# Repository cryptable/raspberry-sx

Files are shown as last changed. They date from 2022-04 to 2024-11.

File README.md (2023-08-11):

# raspberry-sx

Cyberdesck based on old [Commodore 64 SX](https://en.wikipedia.org/wiki/Commodore_SX-64). 

It uses a Raspberry Pi 4 with Wifi and 8Gb memory. There is an SSD attached to it using one of the USB 3.0 ports. The other USB 3.0 is used to attach a USB hub. On the USB 2.0 port is a keyboard attached and the other USB 2.0 port is used for the touch screen. It is powered by a powerbank, which is charged using a power supply. There is much place left in the cyberdeck to add other measuring instruments or a Pi modules cluster. 

It is open-source and you can adapt the design as you wish as long as you send me a pictures of your usage with a explanation of usage. 

And when we meet in person, you can also buy me a beer. 

More information is found under the [docs](./docs/cyberdeck-body.md).

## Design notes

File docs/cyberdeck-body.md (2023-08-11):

Cyber-deck
==========

Introduction
------------

We build a cyberdeck which is modifiable for other to extend. It is designed using a casco, which can be extended using other material.
The casco is designed to be waterproof (rainproof), maybe submergable proof.
It is all 3D printed, but the casco can also industrialised be build. You will a 3D printer with a bed 300x300 and a height 400. 

Casco
-----

The design of casco is done in FreeCAD and found in the .\design-folder. It exists out of a front panel containing the keyboard, a body with a front plate and back plate and a backpanel to store the power cable.

The frontpanel contains the Raspberry Pi, Screen, SSD and USB hub. It also has a place to store a mouse or other things.
The backpanel has the connector for ethernet, a cooler and the connector of the powersupply.

Mainboard and Screen
--------------------
- Raspberry Pi4 8Gb
- Wisecoco 5.5 inch FullHD screen
- Ice Tower

The Rapsberry Pi4 8Gb memory in attached to the Wisecoco 5.5 inch FullHD screen with ontop the Ice Tower. You can reuse all the screws and bolds of the Ice Tower and the Wisecoco screen to attach teh Raspi. You will need to shorten the small screws of the Ice Tower to fin into screws of the Wise coco.

You attach the HDMI connection from the screen to the Raspi, but you don't use the touch screen connection, because we will not sacrifice a USB 3.0 port just for a touch screen. We use a small USB-A to micro USB cable (10cm) to make the connection. We need the USB 3.0 ports for the USB 3.0 SSD and USB hub.

Keyboard
--------

see [keyboard](./cyberdeck-keyboard.md)

Power for cyberdeck
-------------------

Power is delivered by a powerbank supporting USB-PD and able to deliver 30W. The USB-C is used to power the Raspberry Pi with its periferals. This is charged by 70W power supply, which means you can use the powersupply for other usages. The 5V of the powersupply is connected to the micro-USB of the powerbank to charge the powerbank.

References
- MEAN WELL Well 1439455 LRS-75-5 AC Power Supply Block Closed 14A 70W 5 V/DC
- Poweradd Energycell II Powerbank PD 30 W, 26800 mAh Power Bank with Power Delivery

Power on and off
----------------

### Naive implementation

The first try was to powering on and off through a switch, which will shutdown the raspberry Pi. But I couldn't start it again. Also the active cooler on the CPU stayed running, proving the raspberry Pi was still drawing power of the powerbank.

### Second try

I build a latched controlled by a Raspberry Pico (with a small 0.96" displayed attached to it) using a MOSFET to switch on the Raspberry Pi and switch it the powerbank off after a shutdown of the Raspberry Pi.
Due to the voltage drop over the MOSFET, because the Pi with the periferals draws a substantial current, I didn't have enough voltage left to run the Raspberry Pi.

### Third solution

I use a USB-PD supported voltage requestor (DollaTek), which can be set to higher voltage, like 12V. In between comes the latch with the micro-controller and after the latch will a buck converter which will output 5V and power the Raspberry Pi.

### Fourth solution

The micro-controller controls a latching relay.

### References:
- https://www.embeddedcomputing.com/technology/open-source/development-kits/raspberry-pi-power-up-and-shutdown-with-a-physical-button
- DollaTek Snellaadtrigger PD/QC/AFC - ondersteunt vaste spanning 5V 9V 12V 15V 20V van USB-C
- Hailege XL4015 DC-DC Buck Converter Step Down Module 4 ~ 38 V op 1,25 – 36 V 5 A DC-DC verstelbare step-down module XL4015 4 ~ 38 V 96%
- Latching Relay FeatherWing

Lids of Cyberdesk with locks
----------------------------

The lids of the cyberdeck a locked using stainless steel levers.

reference:

- Miuse ZS0307-1 Toggle Latch, Stainless Steel Lever, Lock Cap, Lock for Case Box, Toolbox, Drawer, Cabinet, Chest, Pack of 8
- https://www.thingiverse.com/thing:4094861
- https://www.thingiverse.com/thing:5222235

Mouse case lid idea
-------------------

https://www.thingiverse.com/thing:2609754

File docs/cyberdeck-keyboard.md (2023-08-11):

Introduction
============

USB cable loose:

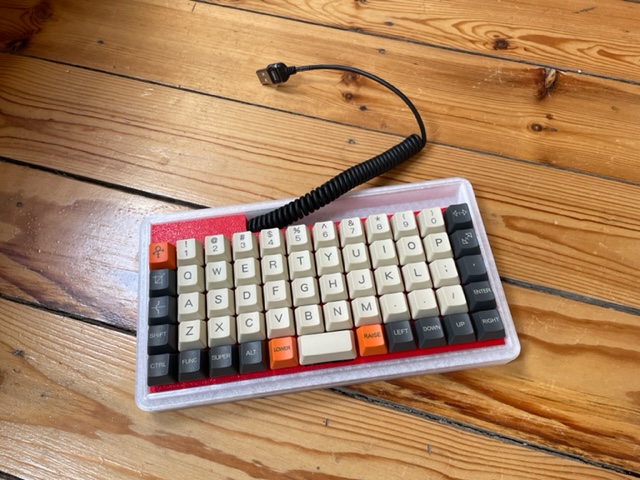
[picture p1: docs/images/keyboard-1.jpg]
Keyboard


USB cable tucked away:

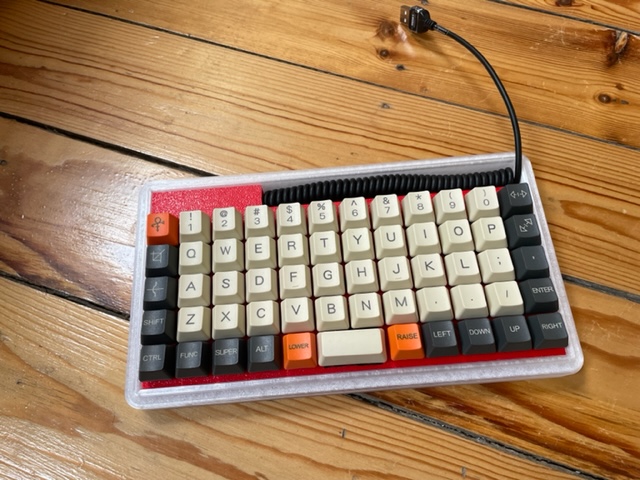
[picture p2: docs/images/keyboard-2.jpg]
Keyboard


The cyberdeck keyboard has:
- JJ50 keyboard backplate
- 59 Cherry green mechanical switches
- 60 red leds
- 5 M2 self tapping screws
- USB kabel Datakabel laadkabel rekbaar spiraalkabel

The keyboard needs 2 3D printed parts:
- bottom case, which will be also the lid of the Cyberdeck. Here it is printed in transparant PETG to give the glowing LEDs on the bottom their nice effect.
- keyboard plate for the switches. The switches need to be soldered on JJ50 backplane. Afterwards the keyboard plate is screwed onto the bottom plate.

Every switch has also its own red led.

Red is the theme here to build the Cherry-Pi cyberdeck.

Improvements:
-------------

This is a kind of todo:

1) Bottom case: Tilt mechanism to tilt the keyboard. Idea: use the hinches to the cyberdeck as a way to tilt it. Can be glued on it afterwards.
2) Keyboard-plate: extract parts on the side to show more of the bottom leds
3) bottom case and keyboard plate: minimize the height (keyboard plate is at 20 mm height from the table)

Building:
---------

### Compiling

references:
- https://beta.docs.qmk.fm/tutorial/newbs_getting_started

### flashing

```
sudo bootloadHID Downloads/jj50_test_jj50.hex
```

BootloadHID flashing jj50
- https://beta.docs.qmk.fm/using-qmk/guides/flashing/flashing_bootloadhid

references:
- https://beta.docs.qmk.fm/using-qmk/guides/flashing/flashing_bootloadhid

### Testing

#### Switches

The MO (7, 4, 5) switches don't show up in the qmk configurator and tester. So to test the switches we will allocate them to some keys from the keypad (1,2,3).

1) in the config.qmk.fm we select the jj50 and load default.
2) Select the MO 7 and click on '1' of the keypad
3) Select the MO 4 and click on '2' of the keypad
4) Select the MO 5 and click on '3' of the keypad

When flashed you can test the switches after removal en reinserting the keyboard. Take into account the MO keys are mapped to the keypad.
To test the keyboard use the keyboard tester of config.qmk.fm and compare it with the layout. It is simpler you print the layout in one browser and open the tester in another browser.
One by one you short the switch to see the correct key lights up.

Note:
* THIS ONLY FOR TESTING THE KEYBOARD TO SEND IT BACK IN CASE OF PROBLEMS !!! *
You need to reflash it afterwards with the default jj50 or your custom firmware.

#### LEDs

The leds underneat will turn on when flashed.

In bootloader mode all leds flashes. So you can test them one-by-one.
The leds underneat are turned off in bootloader mode.

References & parts
------------------

### Ali Express

- Jj50 V1.0 Custom Mechanische Toetsenbord 50% Pcb Geprogrammeerd 50 Preonic Layouts Bface Firmware Met Rgb Bodem Underglow Led (30.67$) https://nl.aliexpress.com/item/32848915277.html?gatewayAdapt=glo2nld&spm=a2g0o.order_list.0.0.21ef79d2P7f0q6
- 7 * 10Pcs/pack Mechanical Keyboard Switch Gateron MX3 Pin Green Switch Transparent Case for Mechanical Keyboard Cherry MX Compatible (17.64$) (https://nl.aliexpress.com/item/1005001728721678.html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)

### Amazon

- 800 Stück M2 schwarzer Kohlenstoffstahl mit Senkkopf und flachem Kreuzkopf, selbstschneidende Schrauben, Maschinenschrauben, Befestigungselemente, Reparaturwerkzeuge (13.99€) (https://www.amazon.de/gp/product/B07RYLM9N2/ref=ppx_yo_dt_b_asin_image_o01_s00?ie=UTF8&psc=1)
- Systeem-S Mini USB kabel Datakabel laadkabel rekbaar spiraalkabel met 90 ° (8.15€) (https://www.amazon.de/gp/product/B00JR6TDTM/ref=ppx_yo_dt_b_asin_title_o05_s00?ie=UTF8&psc=1)
- YIXISI 600 stuks 3 mm LED lichtdiode, LED diodes set, ronde kop LED, 5 kleuren (9.99€) (https://www.amazon.de/gp/product/B08FJ63WKS/ref=ppx_yo_dt_b_asin_title_o05_s01?ie=UTF8&th=1)
- YMDK Carbon-Tastenkappen mit Lasergravur, 1,5 mm PBT für MX Switches Planck Niu40 Preonic Keyboard (17.74€) (https://www.amazon.de/gp/product/B07JKTQJQ7/ref=ppx_yo_dt_b_asin_title_o03_s00?ie=UTF8&th=1)

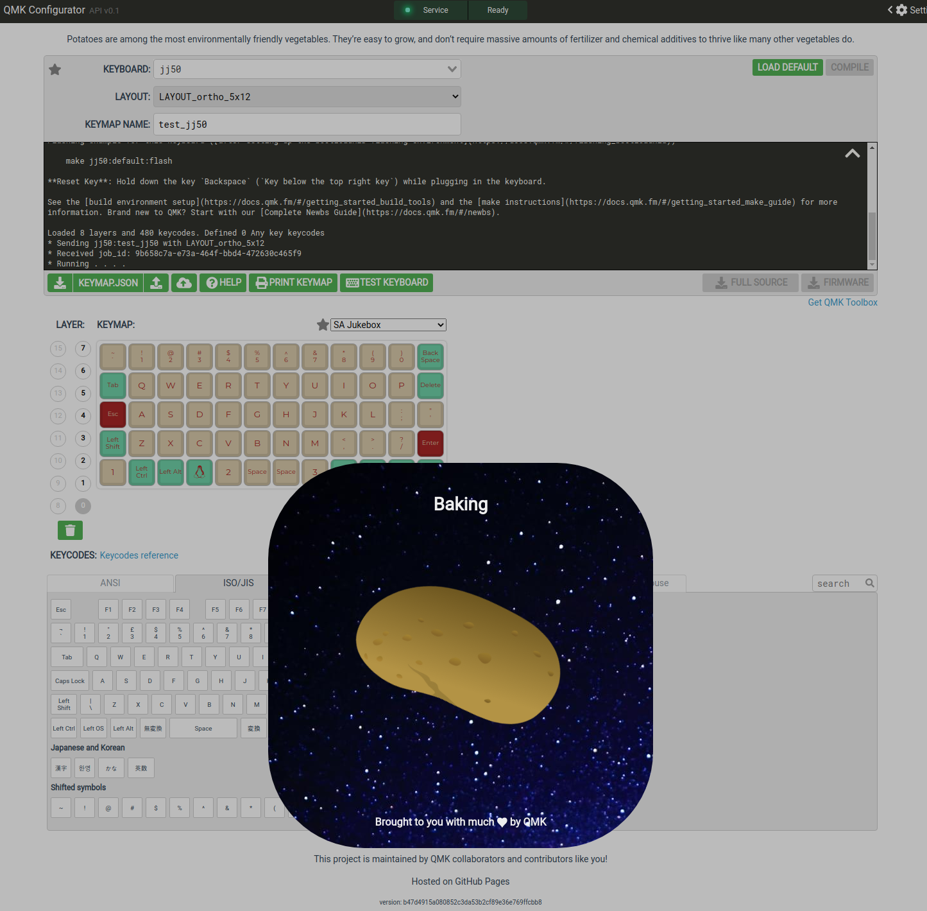
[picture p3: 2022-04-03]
docs/images/2_compile_keymap.png

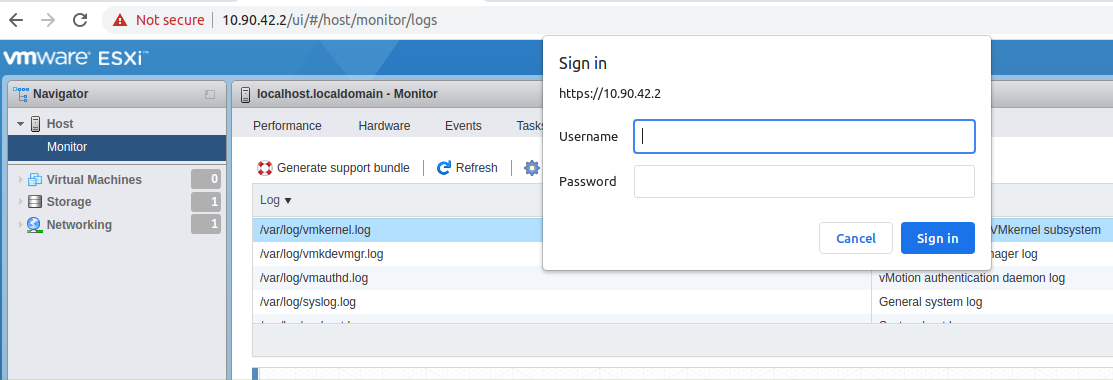
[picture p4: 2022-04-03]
docs/images/Screenshot from 2021-08-28 10-45-59.png

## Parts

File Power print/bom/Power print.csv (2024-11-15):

Reference | Value | Datasheet | Footprint | Qty | DNP
C1 | 1uF | ~ |  | 1
C2 | 10uF | ~ |  | 1
C3,C7,C9 | 100nF | ~ |  | 3
C4 | 33pF | ~ |  | 1
C5 | 22uF | ~ |  | 1
C6,C8 | 10n | ~ |  | 2
D1 | D | https://ngspice.sourceforge.io/docs/ngspice-html-manual/manual.xhtml#cha_DIODEs |  | 1
IC1 | INA3221AIRGVR | http://www.ti.com/lit/ds/symlink/ina3221.pdf | QFN65P400X400X100-17N-D | 1
IC2 | TPS566247DRLR | https://www.ti.com/lit/ds/symlink/tps566247.pdf?ts=1660699623182 | SOTFL50P160X60-6N | 1
J1 | USB_C_Receptacle_USB2.0_14P | https://www.usb.org/sites/default/files/documents/usb_type-c.zip |  | 1
J2 | Microcontroller | ~ |  | 1
J3 | Vout_Connector | ~ |  | 1
L1 | 2.2uH | ~ |  | 1
Q1,Q3 | BC846 | https://assets.nexperia.com/documents/data-sheet/BC846_SER.pdf | Package_TO_SOT_SMD:SOT-23 | 2
Q2 | ZXMP4A16G | https://www.diodes.com/assets/Datasheets/ZXMP4A16G.pdf | Package_TO_SOT_SMD:SOT-223-3_TabPin2 | 1
R1 | 10k | ~ |  | 1
R2 | 1k | ~ | Resistor_SMD:R_0805_2012Metric | 1
R3 | 24k | ~ |  | 1
R4,R5 | 0.1 0.5% | ~ | Resistor_SMD:R_2512_6332Metric | 2
R6 | 100k | ~ |  | 1
R7 | 21.5k | ~ |  | 1
R8 | 220k | ~ |  | 1
R9 | 30k | ~ |  | 1
R10,R12 | 100 | ~ |  | 2
R11,R13,R14 | 100K | ~ |  | 3
R15,R16,R17,R18,R19,R20,R21 | 10K | ~ |  | 7
SW1 | SW_Push | ~ | Connector_PinHeader_1.27mm:PinHeader_1x02_P1.27mm_Vertical | 1
U1 | CH224K | http://www.wch-ic.com/downloads/CH224DS1_PDF.html | tyk_common:ESSOP-10 | 1

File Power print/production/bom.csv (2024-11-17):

Designator | Footprint | Quantity | Value | LCSC Part #
C1 | 1206 | 1 | 1uF | C1848
C2 | 1206 | 1 | 10uF | C1849
C3, C7, C9 | 1206 | 3 | 100nF | C1945
C4 | 1206 | 1 | 33pF | C1906
C5 | 1206 | 1 | 22uF | C12891
C6 | 0805 | 1 | 10n | C1710
D1 | SOT-23 | 1 | BAT54C | C916424
IC1 | QFN-16_L4.0-W4.0-P0.65-TL-EP2.2 | 1 | INA3221AIRGVR | C181255
IC2 | SOT-563 | 1 | TPS566247DRLR | C5219274
J1 | PinHeader_1x03_P1.00mm_Vertical | 1 | Conn_01x03_Pin
J2 | PinHeader_1x07_P1.00mm_Vertical | 1 | Conn_01x07_Pin
J3 | CONN-TH_P5.00_KF301-5.0-2P | 1 | Vout_Connector | C474881
J4 | USB_C_Receptacle_GCT_USB4105-xx-A_16P_TopMnt_Horizontal | 1 | USB_C_Receptacle_USB2.0_16P | C2965608
L1 | IND-SMD_L7.2-W6.6_GPSR07X0 | 1 | 2.2uH | C5189746
Q1 | SOT-23 | 1 | BSS123 | C7420338
Q2 | SOT-223-3_TabPin2 | 1 | ZXMP4A16G | C141324
R1, R15, R17, R18, R19, R20, R21 | 1206 | 7 | 10k | C326700
R10 | 1206 | 1 | 330 | C3013376
R11 | 1210 | 1 | 1M | C470029
R13, R6 | 1206 | 2 | 100K | C606185
R2 | 1206 | 1 | 1k | C2759097
R3 | 1206 | 1 | 24k | C2759176
R4, R5 | 2512 | 2 | 0.1 1% | C7419997
R7 | 1206 | 1 | 21.5k | C311938
R8 | 1210 | 1 | 220k | C606197
R9 | 1206 | 1 | 30k | C3013378
U1 | ESSOP-10_L4.9-W3.9-P1.0-LS6.0-TL-EP | 1 | CH224K | C970725

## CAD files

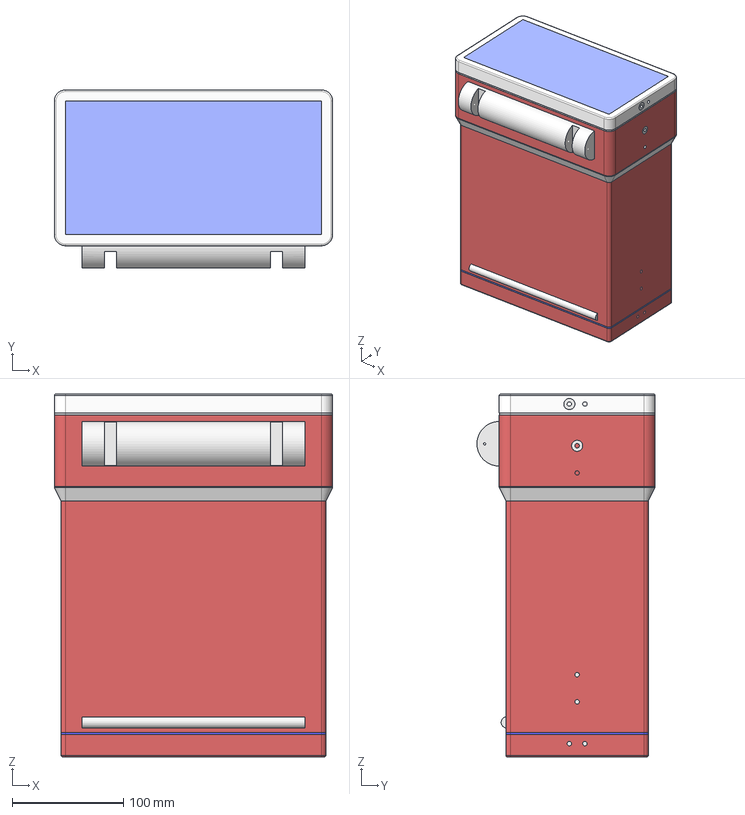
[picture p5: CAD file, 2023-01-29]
design/Cyberdeck.FCStd
250.0 x 160.0 x 326.0 mm
KeybBottomPlate
Fitter
Tube
Tube001
Tube002
Tube003
Tube004
Lockhole003
Lockhole004
Lockhole007
Lockhole008
SlentedBorder
Power Supply standoffs
Battery case
lockhole001
Lockhole002
Lockhole005
Lockhole006
Lockhole010
Lockhole009
Lockhole013
Lockhole014
BorderBodyCut
MaincaseWithHoles
Lockhole012
Lockhole011
Lockhole015
Lockhole016

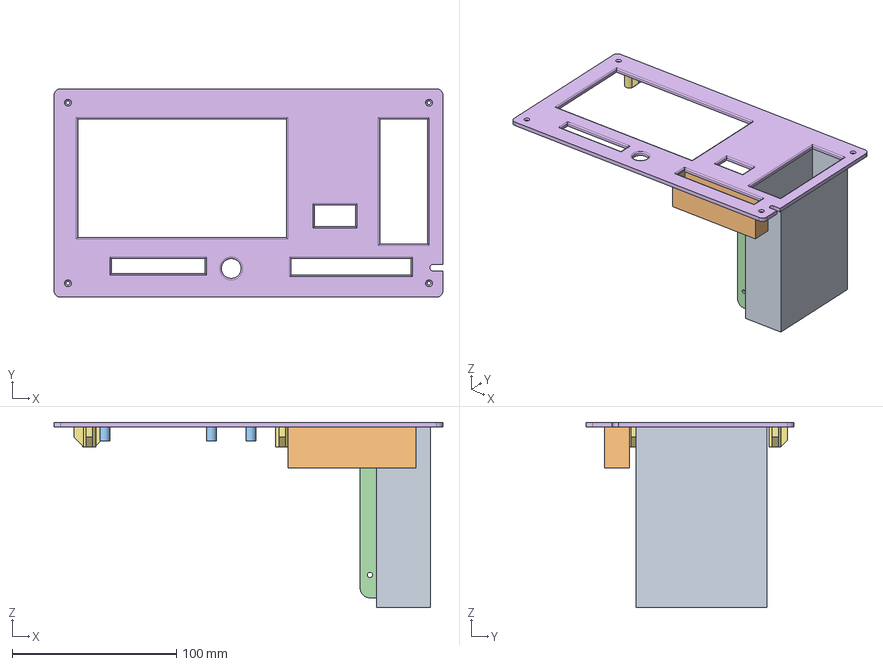
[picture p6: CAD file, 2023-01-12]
design/Panels.FCStd
237.0 x 127.0 x 113.0 mm
MouseCase
USBCase
Standoffs Printplate
ssd-left
ssd-right
Main Front
RaspberryPi Standoffs

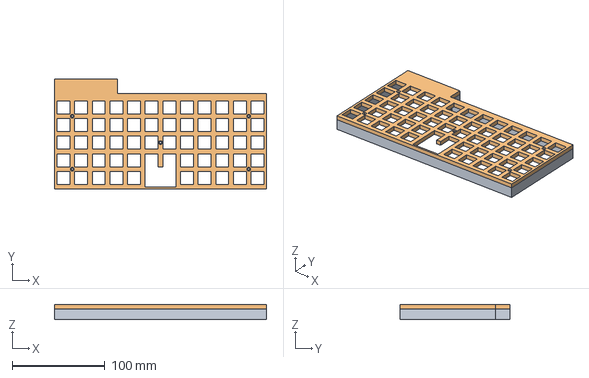
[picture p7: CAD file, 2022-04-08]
design/Keyboard.FCStd
229.0 x 119.0 x 16.0 mm

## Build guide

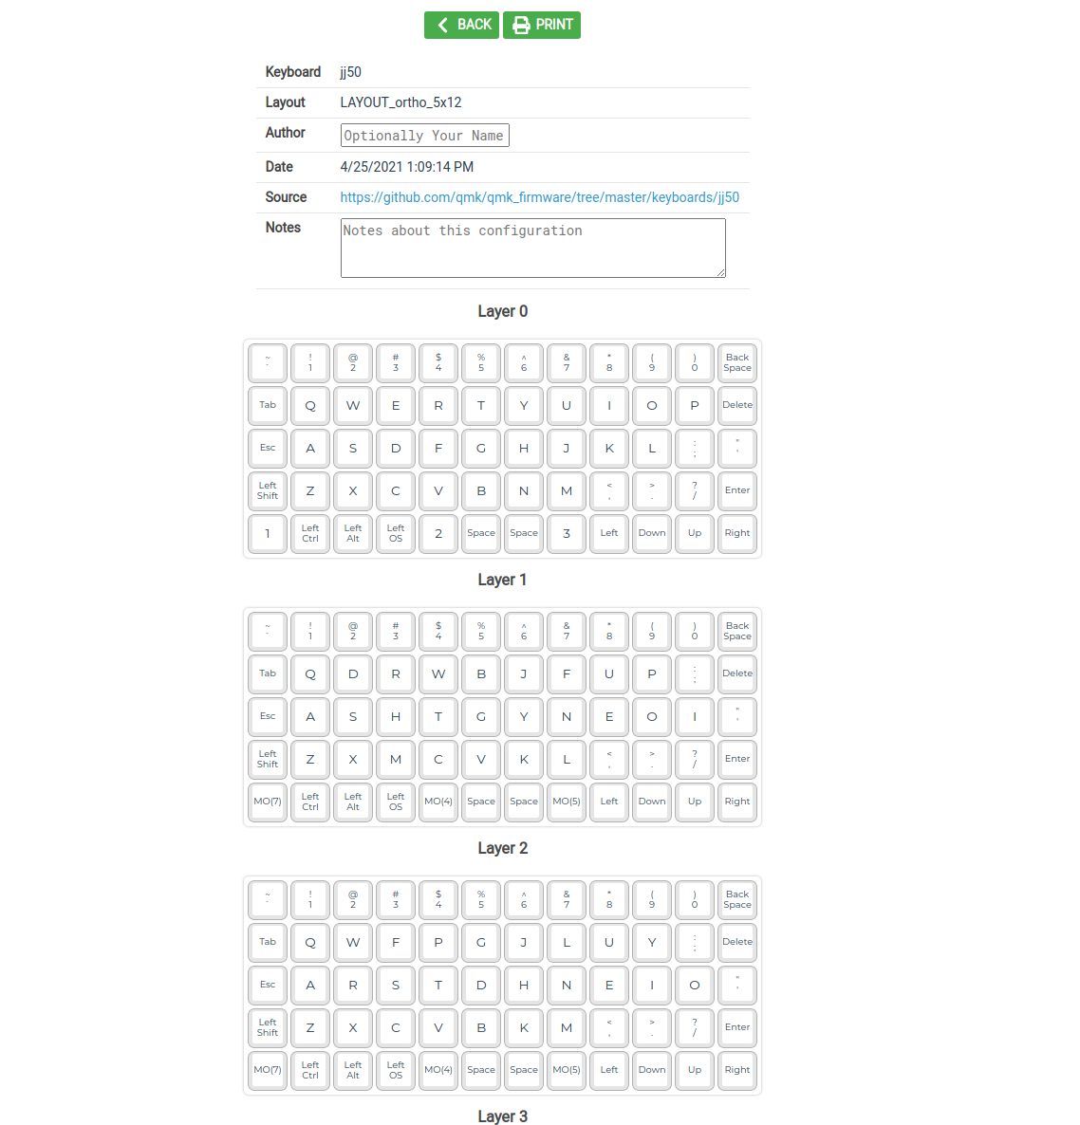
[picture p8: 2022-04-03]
docs/images/5_print-keymap.png

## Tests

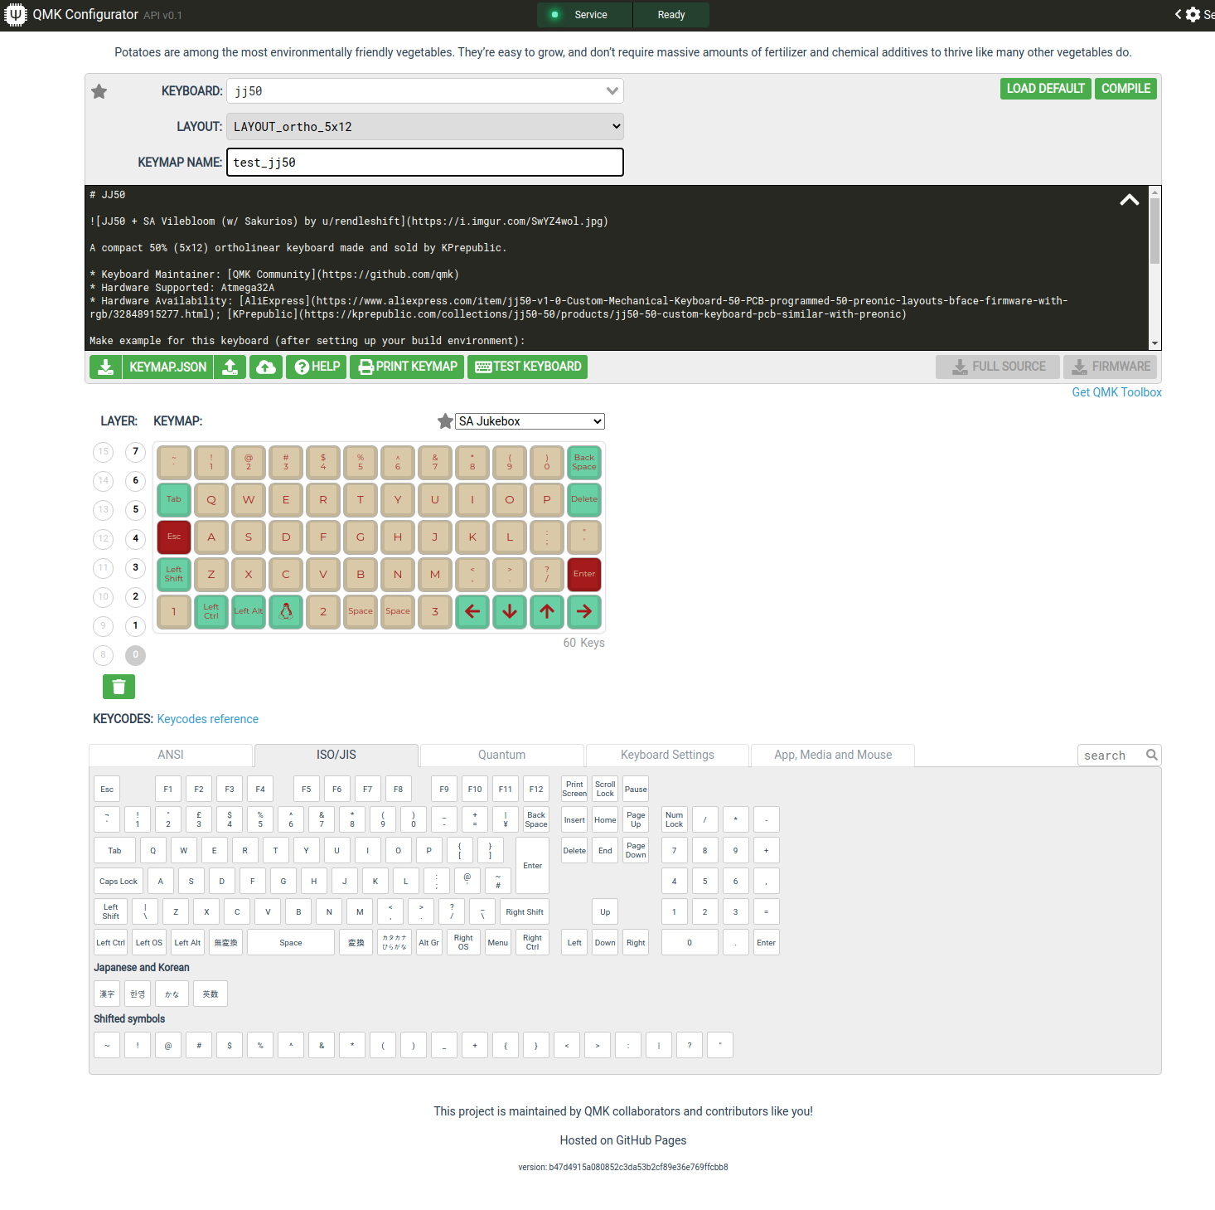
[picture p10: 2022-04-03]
docs/images/1_keyboard-mapping-test.png

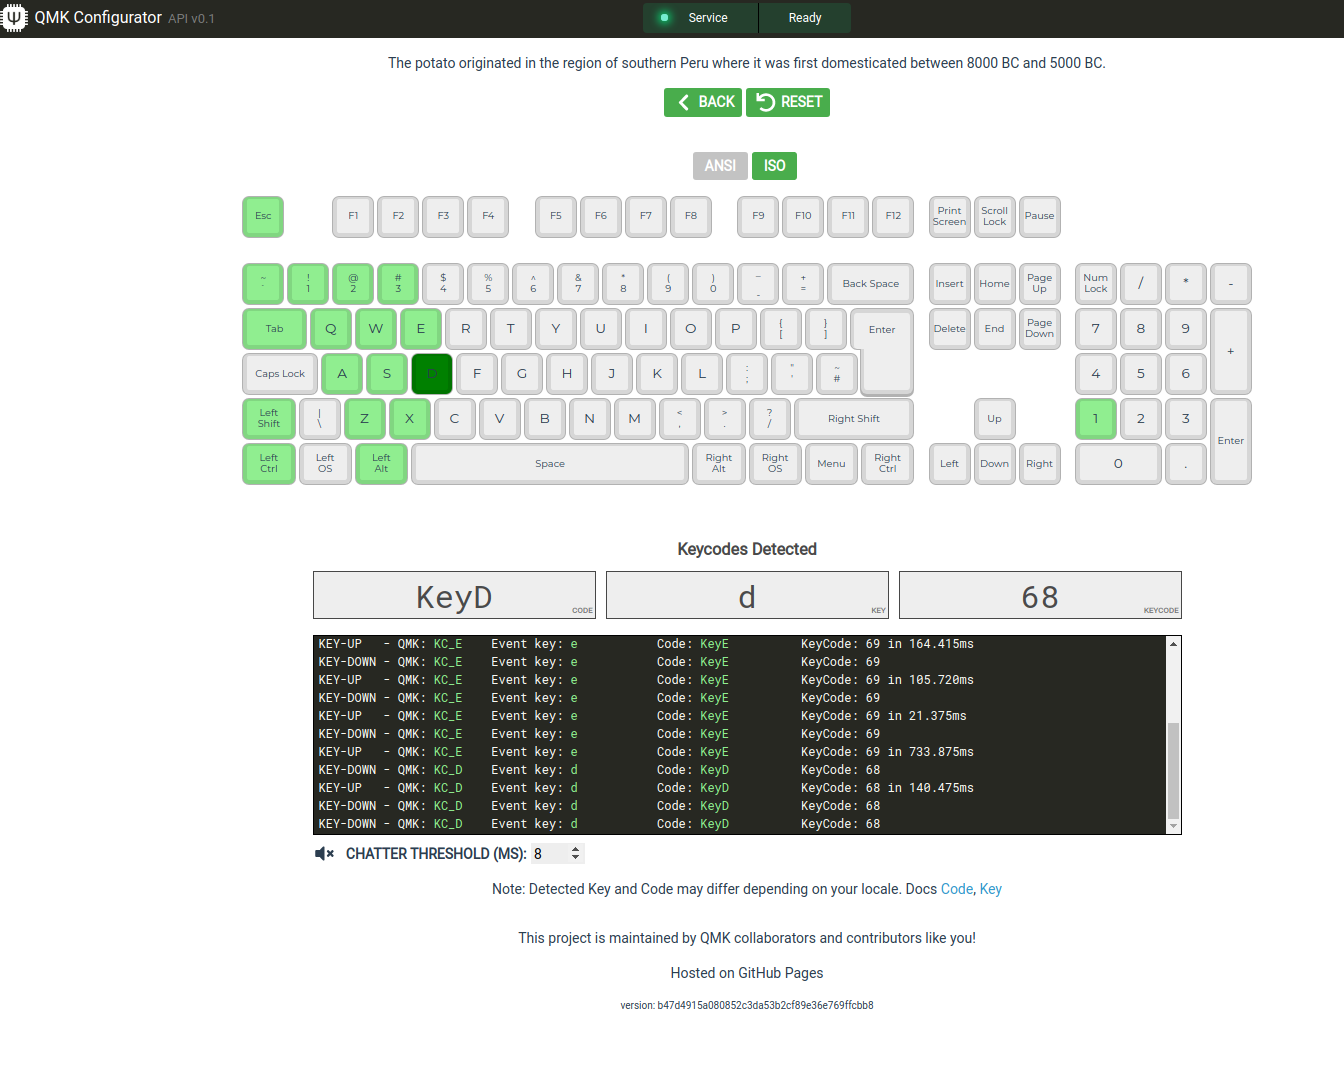
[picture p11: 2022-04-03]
docs/images/testing-keyboard.png

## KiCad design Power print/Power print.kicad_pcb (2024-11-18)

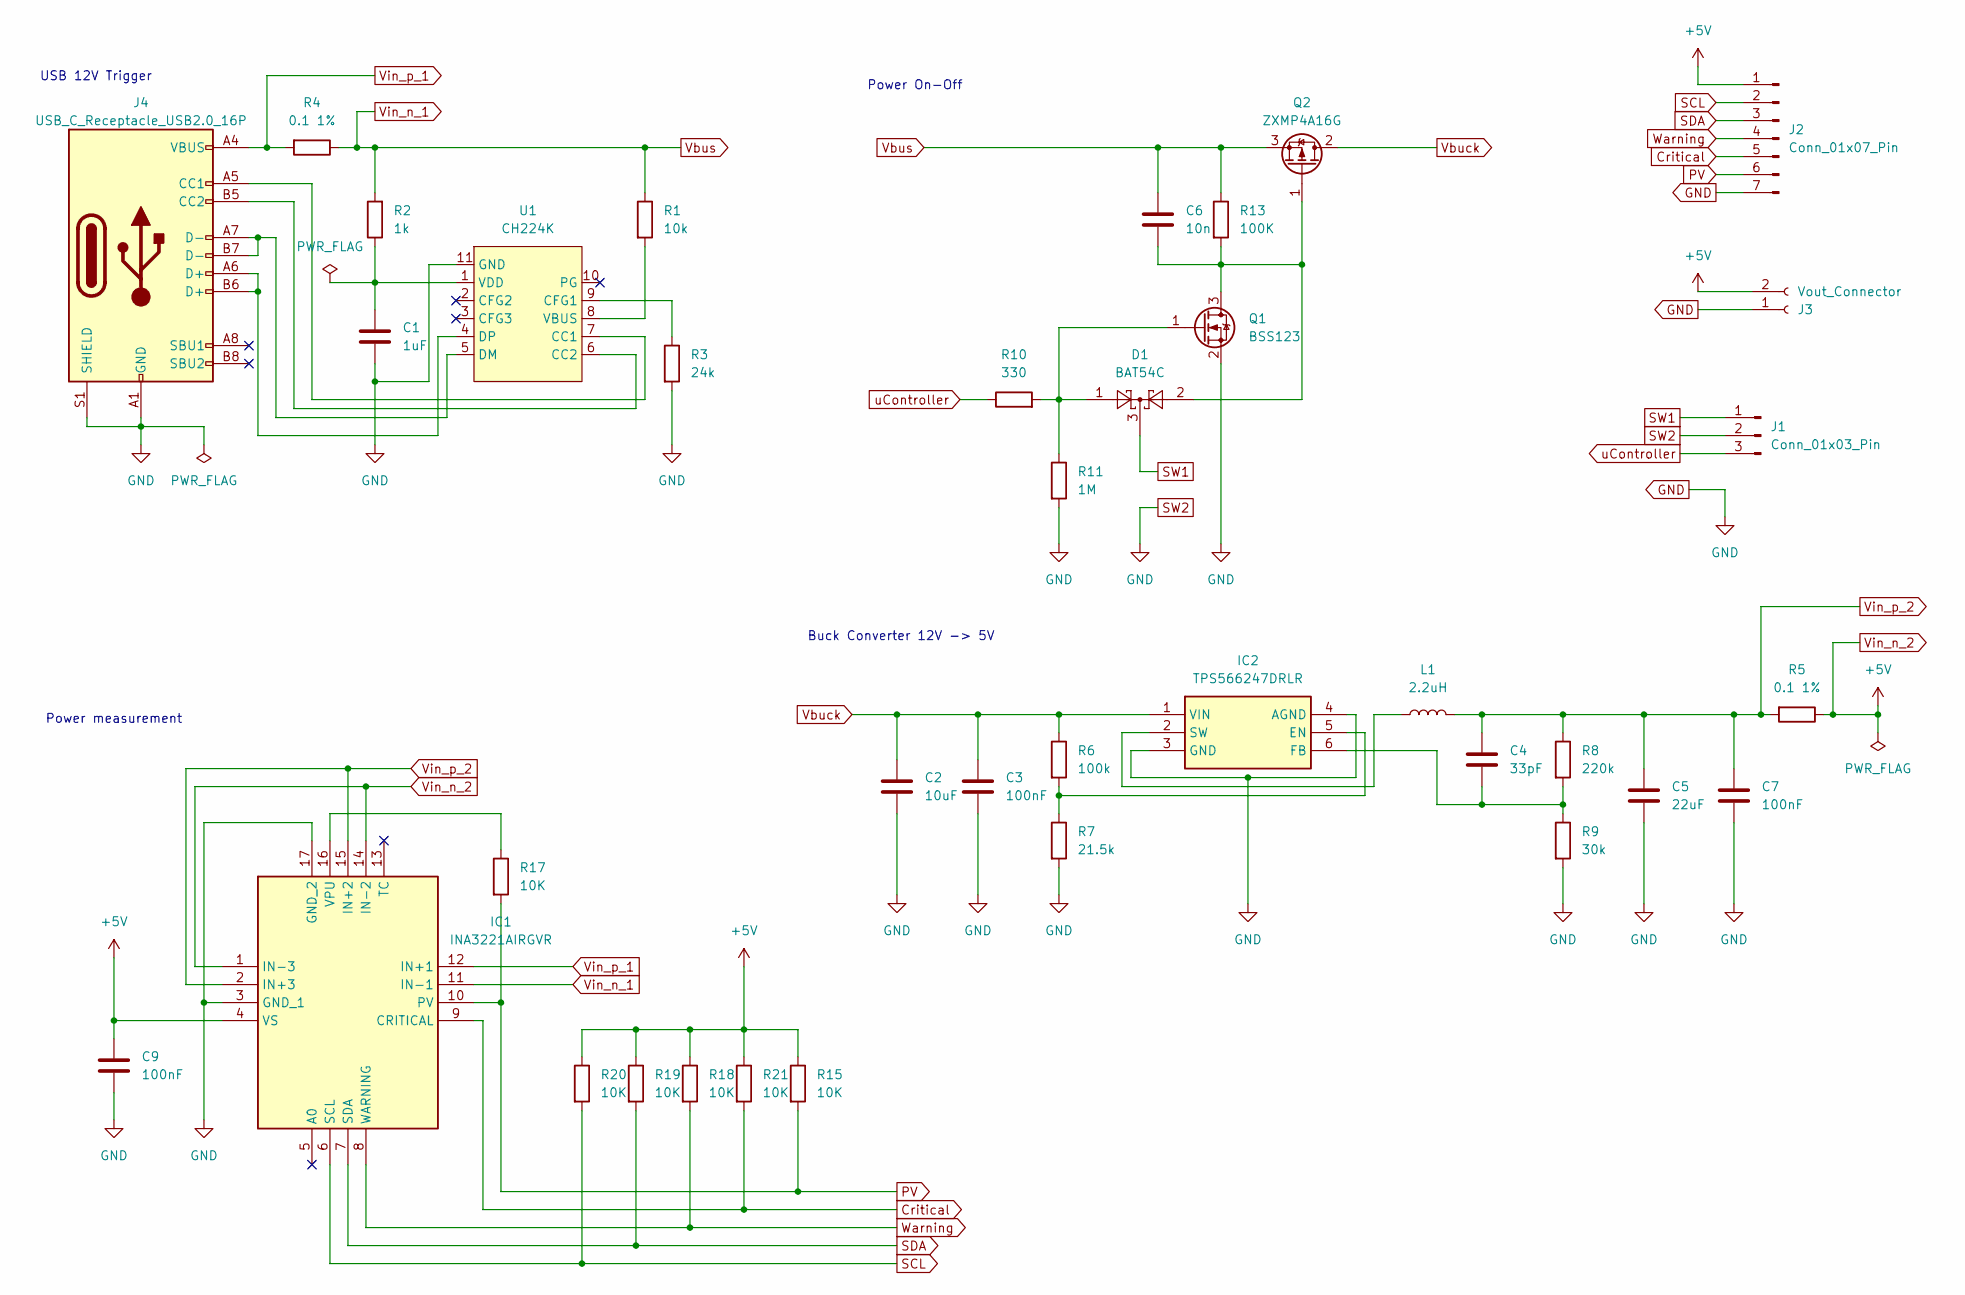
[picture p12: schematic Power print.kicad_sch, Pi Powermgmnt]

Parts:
C1: 1uF; C_1206_3216Metric_Pad1.33x1.80mm_HandSolder; LCSC C1848
C2: 10uF; C_1206_3216Metric_Pad1.33x1.80mm_HandSolder; LCSC C1849
C3, C7, C9: 100nF; C_1206_3216Metric_Pad1.33x1.80mm_HandSolder; LCSC C1945
C4: 33pF; C_1206_3216Metric_Pad1.33x1.80mm_HandSolder; LCSC C1906
C5: 22uF; C_1206_3216Metric_Pad1.33x1.80mm_HandSolder; LCSC C12891
C6: 10n; C_0805_2012Metric_Pad1.18x1.45mm_HandSolder; LCSC C1710
D1: BAT54C; SOT-23; LCSC C916424
IC1: INA3221AIRGVR; QFN-16_L4.0-W4.0-P0.65-TL-EP2.2; Manufacturer_Part_Number INA3221AIRGVR; LCSC C181255
IC2: TPS566247DRLR; SOT-563; Manufacturer_Part_Number TPS566247DRLR; LCSC C5219274
J1: Conn_01x03_Pin; PinHeader_1x03_P1.00mm_Vertical
J2: Conn_01x07_Pin; PinHeader_1x07_P1.00mm_Vertical
J3: Vout_Connector; CONN-TH_P5.00_KF301-5.0-2P; LCSC C474881
J4: USB_C_Receptacle_USB2.0_16P; USB_C_Receptacle_GCT_USB4105-xx-A_16P_TopMnt_Horizontal; LCSC C2965608
L1: 2.2uH; IND-SMD_L7.2-W6.6_GPSR07X0; LCSC C5189746
Q1: BSS123; SOT-23; LCSC C7420338
Q2: ZXMP4A16G; SOT-223-3_TabPin2; LCSC C141324
R1: 10k; R_1206_3216Metric_Pad1.30x1.75mm_HandSolder; LCSC C326700
R2: 1k; R_1206_3216Metric_Pad1.30x1.75mm_HandSolder; LCSC C2759097
R3: 24k; R_1206_3216Metric_Pad1.30x1.75mm_HandSolder; LCSC C2759176
R4, R5: 0.1 1%; R_2512_6332Metric_Pad1.40x3.35mm_HandSolder; LCSC C7419997
R6: 100k; R_1206_3216Metric_Pad1.30x1.75mm_HandSolder; LCSC C606185
R7: 21.5k; R_1206_3216Metric_Pad1.30x1.75mm_HandSolder; LCSC C311938
R8: 220k; R_1210_3225Metric_Pad1.30x2.65mm_HandSolder; LCSC C606197
R9: 30k; R_1206_3216Metric_Pad1.30x1.75mm_HandSolder; LCSC C3013378
R10: 330; R_1206_3216Metric_Pad1.30x1.75mm_HandSolder; LCSC C3013376
R11: 1M; R_1210_3225Metric_Pad1.30x2.65mm_HandSolder; LCSC C470029
R13: 100K; R_1206_3216Metric_Pad1.30x1.75mm_HandSolder; LCSC C606185
R15, R17, R18, R19, R20, R21: 10K; R_1206_3216Metric_Pad1.30x1.75mm_HandSolder; LCSC C326700
U1: CH224K; ESSOP-10_L4.9-W3.9-P1.0-LS6.0-TL-EP; LCSC C970725

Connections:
Critical: IC1.9 (CRITICAL), J2.5, R21.2
GND: C1.2, C2.2, C3.2, C5.2, C7.2, C9.2, IC1.3 (GND_1), IC1.17 (GND_2), IC2.3 (GND), IC2.4 (AGND), J1.2, J2.7, J3.1, J4.A1 (GND), J4.A12 (GND), J4.B1 (GND), J4.B12 (GND), J4.S1 (SHIELD), Q1.2 (S), R3.2, R7.2, R9.2, R11.2, U1.11 (GND)
unnamed: IC1.16 (VPU), R17.1
unnamed: IC2.5 (EN), R6.2, R7.1
unnamed: C4.2, IC2.6 (FB), R8.2, R9.1
unnamed: IC2.2 (SW), L1.1
unnamed: J4.A5 (CC1), U1.7 (CC1)
unnamed: J4.B5 (CC2), U1.6 (CC2)
unnamed: C6.2, D1.2, Q1.3 (D), Q2.1 (G), R13.2
unnamed: D1.1, Q1.1 (G), R10.2, R11.1
unnamed: R3.1, U1.9 (CFG1)
unnamed: J4.A7 (D-), J4.B7 (D-), U1.5 (DM)
unnamed: J4.A6 (D+), J4.B6 (D+), U1.4 (DP)
unnamed: R1.2, U1.8 (VBUS)
unnamed: C1.1, R2.1, U1.1 (VDD)
PV: IC1.10 (PV), J2.6, R15.2, R17.2
SCL: IC1.6 (SCL), J2.2, R20.2
SDA: IC1.7 (SDA), J2.3, R19.2
SW1: D1.3, J1.1
Vbuck: C2.1, C3.1, IC2.1 (VIN), Q2.2 (D), R6.1
Vbus: C6.1, IC1.11 (IN-1), Q2.3 (S), R1.1, R2.2, R4.1, R13.1
Vin_n_2: C9.1, IC1.1 (IN-3), IC1.4 (VS), IC1.14 (IN-2), J2.1, J3.2, R5.1, R15.1, R18.1, R19.1, R20.1, R21.1
Vin_p_1: IC1.12 (IN+1), J4.A4 (VBUS), J4.A9 (VBUS), J4.B4 (VBUS), J4.B9 (VBUS), R4.2
Vin_p_2: C4.1, C5.1, C7.1, IC1.2 (IN+3), IC1.15 (IN+2), L1.2, R5.2, R8.1
Warning: IC1.8 (WARNING), J2.4, R18.2
uController: J1.3, R10.1

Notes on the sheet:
Power On-Off
USB 12V Trigger
Power measurement
Buck Converter 12V -> 5V

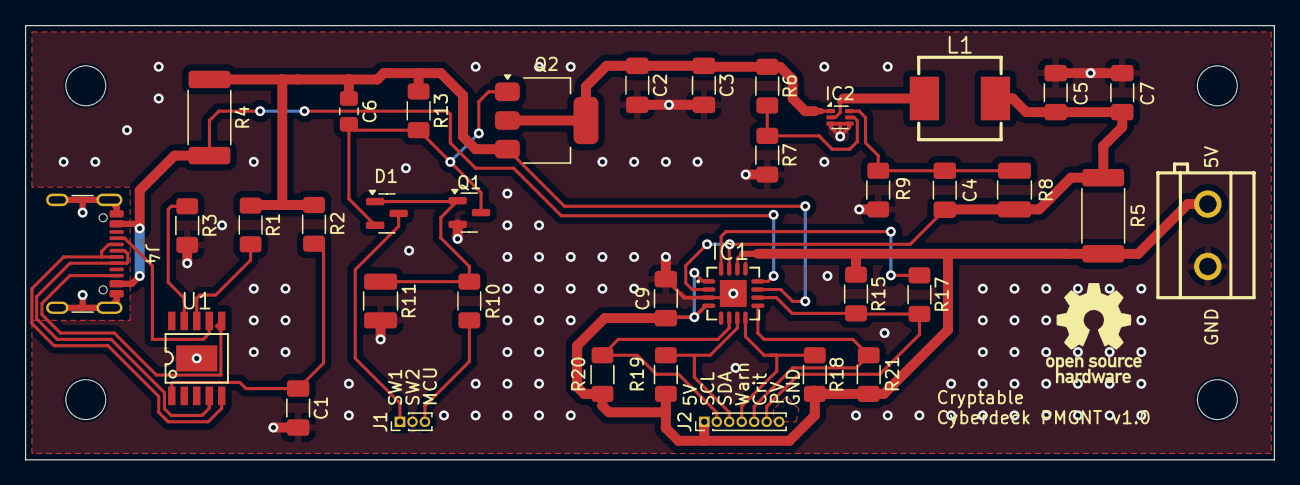
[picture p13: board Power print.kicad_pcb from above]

Board: 2 copper layers, 100.1 x 34.8 mm, 37 parts (0 on the bottom side), 26 nets.

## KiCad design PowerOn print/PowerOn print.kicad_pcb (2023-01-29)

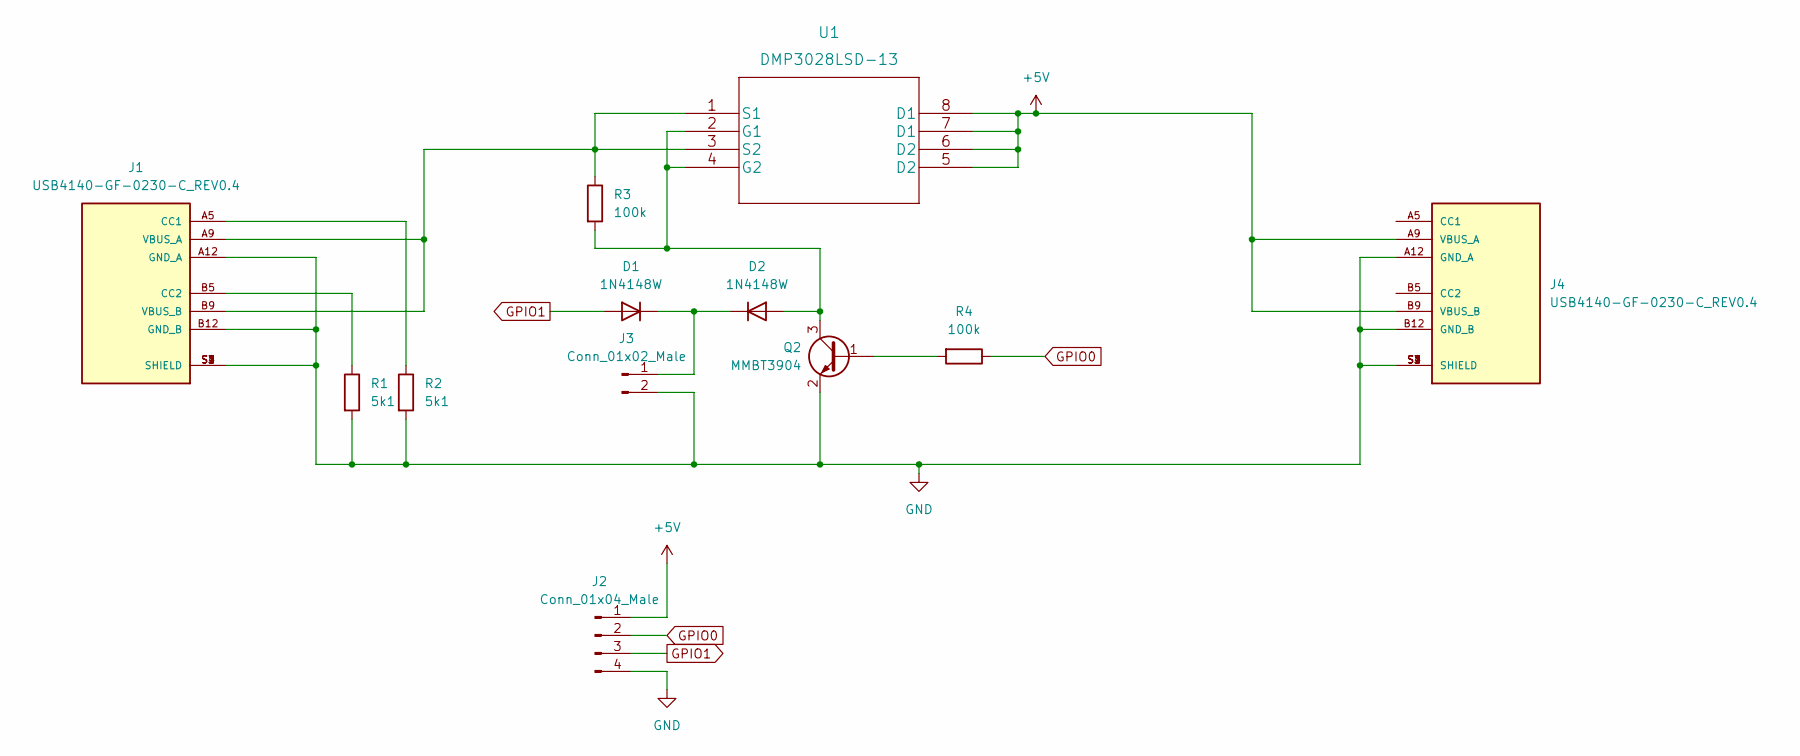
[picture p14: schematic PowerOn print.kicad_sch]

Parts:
D1, D2: 1N4148W; D_SOD-123
J1, J4: USB4140-GF-0230-C_REV0.4; GCT_USB4140-GF-0230-C_REV0.4; PARTREV 0.4
J2: Conn_01x04_Male; PinHeader_1x04_P2.54mm_Vertical
J3: Conn_01x02_Male; PinHeader_1x02_P2.54mm_Vertical
Q2: MMBT3904; SOT-23
R1, R2: 5k1; R_0805_2012Metric
R3, R4: 100k; R_0805_2012Metric
U1: DMP3028LSD-13

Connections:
+5V: J2.1, J4.A9 (VBUS_A), J4.B9 (VBUS_B), U1.5 (D2), U1.6 (D2), U1.7 (D1), U1.8 (D1)
GND: J1.A12 (GND_A), J1.B12 (GND_B), J1.S1 (SHIELD), J1.S2 (SHIELD), J1.S3 (SHIELD), J1.S4 (SHIELD), J2.4, J3.2, J4.A12 (GND_A), J4.B12 (GND_B), J4.S1 (SHIELD), J4.S2 (SHIELD), J4.S3 (SHIELD), J4.S4 (SHIELD), Q2.2 (E), R1.2, R2.2
GPIO0: J2.2, R4.1
GPIO1: D1.2 (A), J2.3
unnamed: D1.1 (K), D2.1 (K), J3.1
unnamed: D2.2 (A), Q2.3 (C), R3.2, U1.2 (G1), U1.4 (G2)
unnamed: J1.A5 (CC1), R2.1
unnamed: J1.A9 (VBUS_A), J1.B9 (VBUS_B), R3.1, U1.1 (S1), U1.3 (S2)
unnamed: J1.B5 (CC2), R1.1
unnamed: Q2.1 (B), R4.2

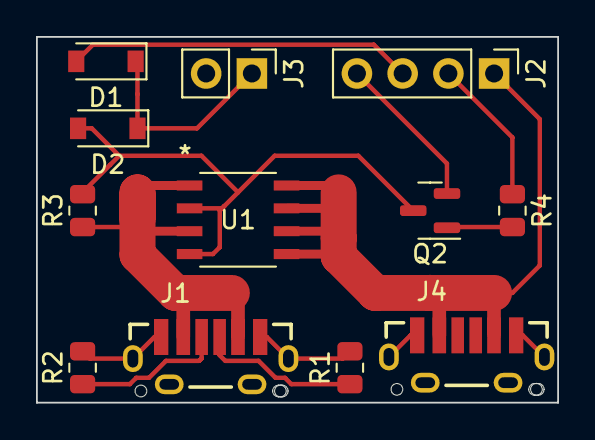
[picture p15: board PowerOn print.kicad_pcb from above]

Board: 2 copper layers, 29.0 x 20.3 mm, 12 parts (0 on the bottom side), 10 nets.

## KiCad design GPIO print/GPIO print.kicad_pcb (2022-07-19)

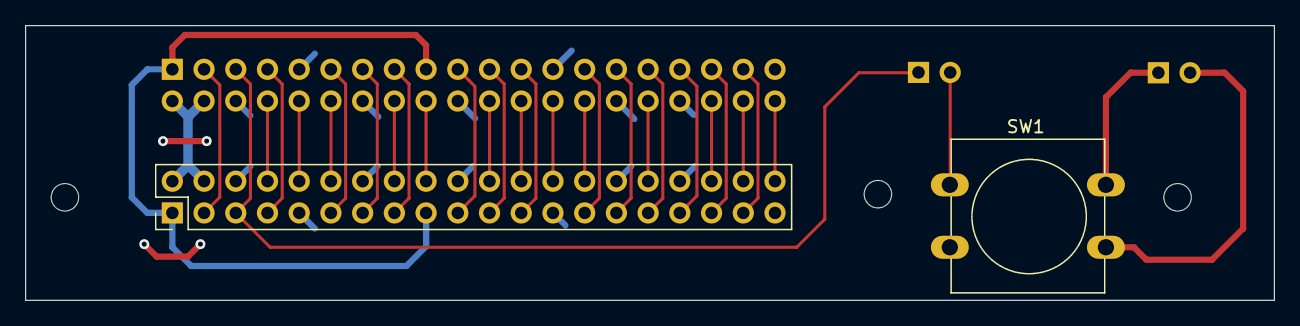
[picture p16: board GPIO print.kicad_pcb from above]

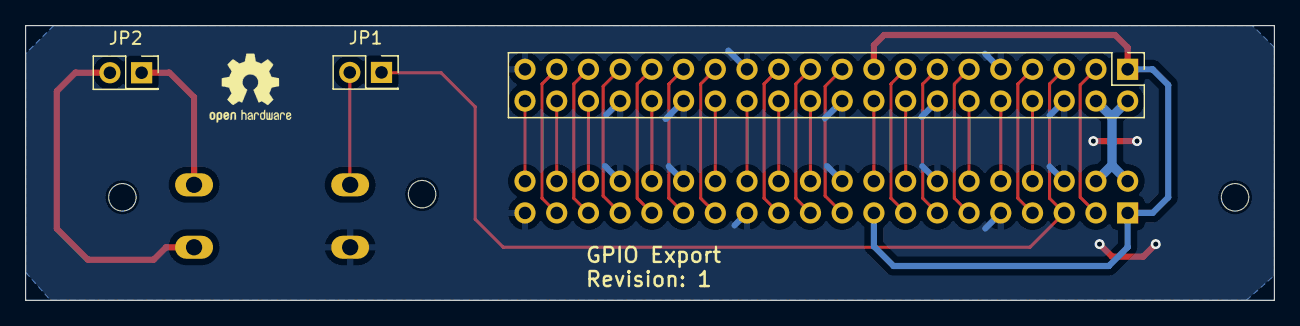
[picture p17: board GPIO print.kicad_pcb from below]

Board: 2 copper layers, 100.0 x 22.0 mm, 5 parts (3 on the bottom side), 34 nets.

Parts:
J1: Raspberry Out; PinHeader_2x20_P2.54mm_Vertical
J2: Raspberry In; PinHeader_2x20_P2.54mm_Vertical
JP1: Power Option; PinSocket_2x01_P2.54mm_Vertical
JP2: Other Option; PinSocket_2x01_P2.54mm_Vertical
SW1: Power Switch; SW_PUSH-12mm

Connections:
/3V3: J1.1, J1.17, J2.1, J2.17
/5V: J1.2, J1.4, J2.2, J2.4
/GPIO2: J1.3, J2.3
/GPIO4: J1.7, J2.7
/GPIO5: J1.29, J2.29
/GPIO6: J1.31, J2.31
/GPIO7: J1.26, J2.26
/GPIO8: J1.24, J2.24
/GPIO9: J1.21, J2.21
/GPIO10: J1.19, J2.19
/GPIO11: J1.23, J2.23
/GPIO12: J1.32, J2.32
/GPIO13: J1.33, J2.33
/GPIO14: J1.8, J2.8
/GPIO15: J1.10, J2.10
/GPIO16: J1.36, J2.36
/GPIO17: J1.11, J2.11
/GPIO18: J1.12, J2.12
/GPIO19: J1.35, J2.35
/GPIO20: J1.38, J2.38
/GPIO21: J1.40, J2.40
/GPIO22: J1.15, J2.15
/GPIO23: J1.16, J2.16
/GPIO24: J1.18, J2.18
/GPIO25: J1.22, J2.22
/GPIO26: J1.37, J2.37
/GPIO27: J1.13, J2.13
/ID_SC: J1.28, J2.28
/ID_SD: J1.27, J2.27
GND: J1.6, J1.9, J1.14, J1.20, J1.25, J1.30, J1.34, J1.39, J2.6, J2.9, J2.14, J2.20, J2.25, J2.30, J2.34, J2.39, SW1.2
GPIO3: J1.5, J2.5, JP1.1 (A)
unnamed: JP1.2 (B), SW1.1
unnamed: JP2.1 (A), SW1.3
unnamed: JP2.2 (B), SW1.4

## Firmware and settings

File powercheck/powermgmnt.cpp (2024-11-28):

/**
 * Copyright (c) 2020 Raspberry Pi (Trading) Ltd.
 *
 * SPDX-License-Identifier: BSD-3-Clause
 */
#include "pico/stdlib.h"
#include "hardware/i2c.h"
#include "pico/binary_info.h"
#include "powerdisplay.hpp"

#define  WAIT_UNTIL_POWERDOWN_IN_MS 10000
#define  POWERDOWN_PIN              14
#define  POWERDOWN_BUTTON_PIN       2
#define  POWERDOWN_PI_PIN           3

#define  INA3221_SDA                0
#define  INA3221_SCL                1

#define  INA3221_CRIT               11
#define  INA3221_WARN               10
#define  INA3221_PV                 12


// Powerdown to stop RP2040
bool done = false;
Powerdisplay *p_display = NULL;
int timer = WAIT_UNTIL_POWERDOWN_IN_MS / 1000;

int64_t alarm_powerdown(alarm_id_t id, void *user_data);

void gpio_irq_powerdown(uint gpio, uint32_t event_mask);

// I2C reserves some addresses for special purposes. We exclude these from the scan.
// These are any addresses of the form 000 0xxx or 111 1xxx
bool reserved_addr(uint8_t addr) {
    return (addr & 0x78) == 0 || (addr & 0x78) == 0x78;
}

int main() {
    i2c_init(i2c_default, 100 * 1000);
    gpio_set_function(INA3221_SDA, GPIO_FUNC_I2C);
    gpio_set_function(INA3221_SCL, GPIO_FUNC_I2C);
    gpio_pull_up(INA3221_SDA);
    gpio_pull_up(INA3221_SCL);

    gpio_init(POWERDOWN_PIN);
    gpio_set_dir(POWERDOWN_PIN, GPIO_OUT);
//    gpio_pull_up(POWERDOWN_PIN);
    gpio_put(POWERDOWN_PIN,1);


    gpio_init(INA3221_PV);
    gpio_set_dir(INA3221_PV, GPIO_IN);
    gpio_pull_up(INA3221_PV);

    gpio_init(INA3221_CRIT);
    gpio_set_dir(INA3221_CRIT, GPIO_IN);
    gpio_pull_up(INA3221_CRIT);

    gpio_init(INA3221_WARN);
    gpio_set_dir(INA3221_WARN, GPIO_IN);
    gpio_pull_up(INA3221_WARN);

    gpio_init(POWERDOWN_BUTTON_PIN);
    gpio_set_dir(POWERDOWN_BUTTON_PIN, GPIO_IN);
    gpio_set_pulls(POWERDOWN_BUTTON_PIN, true, false);
    gpio_set_irq_enabled_with_callback(POWERDOWN_BUTTON_PIN, GPIO_IRQ_EDGE_FALL, true, gpio_irq_powerdown);

    gpio_init(POWERDOWN_PI_PIN);
    gpio_set_dir(POWERDOWN_PI_PIN, GPIO_OUT);
    gpio_put(POWERDOWN_PI_PIN, 0);

    // Display
    auto display = Powerdisplay();
    p_display = &display;
    p_display->powerdata(12.5, 2.45, 5.02, 4.44);
    while (!done) {
 //       tight_loop_contents();

    // BEGIN : I2C scan
    // Enable UART so we can print status output
    stdio_init_all();
    // Make the I2C pins available to picotool
    bi_decl(bi_2pins_with_func(PICO_DEFAULT_I2C_SDA_PIN, PICO_DEFAULT_I2C_SCL_PIN, GPIO_FUNC_I2C));
    
    printf("\nI2C Bus Scan\n");
    printf("   0  1  2  3  4  5  6  7  8  9  A  B  C  D  E  F\n");

    for (int addr = 0; addr < (1 << 7); ++addr) {
        if (addr % 16 == 0) {
            printf("%02x ", addr);
        }

        // Perform a 1-byte dummy read from the probe address. If a slave
        // acknowledges this address, the function returns the number of bytes
        // transferred. If the address byte is ignored, the function returns
        // -1.

        // Skip over any reserved addresses.
        int ret;
        uint8_t rxdata;
        if (reserved_addr(addr))
            ret = PICO_ERROR_GENERIC;
        else
            ret = i2c_read_blocking(i2c_default, addr, &rxdata, 1, false);

        printf(ret < 0 ? "." : "@");
        printf(addr % 16 == 15 ? "\n" : "  ");
    }
    printf("Done.\n");
    // END I2C scan

    sleep_ms(1000);
   }

    return 0;
}

int64_t alarm_powerdown(alarm_id_t id, void *user_data) {
    if (timer < 0) {
        gpio_put(POWERDOWN_PIN, 0);
        done = true;
        return 0;
    }

    char text[3]={0x00};
    sprintf(text,"%d",timer);
    p_display->countdown(text);
    timer--;
    add_alarm_in_ms(1000, alarm_powerdown, NULL, false);

    return 0;
}

void gpio_irq_powerdown(uint gpio, uint32_t event_mask) {
    add_alarm_in_ms(1000, alarm_powerdown, NULL, false);
    gpio_put(POWERDOWN_PI_PIN, 1);
}

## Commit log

2022-04-03 Initial Cyberdesk
    [Cyberdeck.FCStd, Keyboard.FCStd, Panels.FCStd]
2022-04-04 Change height to 120 mm
    [Cyberdeck.FCStd, Keyboard.FCStd, Panels.FCStd]
2022-04-05 Screen holders
    [Panels.FCStd]
2022-04-05 Screw holes for frontplane
    [Cyberdeck.FCStd, Panels.FCStd]
2022-04-06 Moved keyboard plane 3 mm
    [Cyberdeck.FCStd, Keyboard.FCStd, Panels.FCStd]
2022-04-06 Moved the keyboard to fit the JJ50 and keys
    [Cyberdeck.FCStd, Keyboard.FCStd]
2022-04-06 Chamfer the panel
    [Panels.FCStd]
2022-04-06 Print keyboard
    [Cyberdeck.FCStd]
2022-04-07 Fix Keyboard tubes, which were floating
    [Cyberdeck.FCStd]
2022-04-08 Some small changes
    [Cyberdeck.FCStd, Keyboard.FCStd]
2022-04-08 Spacebar support
    [Keyboard.FCStd]
2022-04-22 Keyboard text
    [Cyberdeck.FCStd]
2022-07-10 Adjust panels
    [Panels.FCStd]
2022-07-10 New USB carrier
    [Panels.FCStd]
2022-07-11 sdd case
    [Panels.FCStd]
2022-07-11 Added Logo and keyboard cable entry
    [Panels.FCStd]
2022-07-13 add print for switch and GPIO
    [GPIO print.kicad_pcb, GPIO print.kicad_sch]
2022-07-13 Add rubber sealing for screen
    [Panels.FCStd]
2022-07-17 Added lock holes to main body
    [Cyberdeck.FCStd]
2022-07-18 Lockholes for bottom
    [Cyberdeck.FCStd]
2022-07-19 Front standoffs
    [Cyberdeck.FCStd]
2022-07-19 Started sketch back panel
    [GPIO print.kicad_pcb, Panels.FCStd]
2022-07-21 back panel
    [Panels.FCStd]
2022-07-21 back panel chmfer and fillet
    [Panels.FCStd]
2022-07-21 Lock misplacement
    [Cyberdeck.FCStd]
2022-07-28 Bigger keyboard cavety
    [Cyberdeck.FCStd]
2022-07-28 Fixed bug in chamfer for backplane
    [Panels.FCStd]
2022-07-28 Backpanel screws of ventilator
    [Panels.FCStd]
2022-07-28 Backpanel move keystone RJ45 up (collided with battery-pack)
    [Panels.FCStd]
2022-08-08 Higher network connector to prevent collission with battery pack
    [Panels.FCStd]
2022-08-08 Sealings added
    [Cyberdeck.FCStd]
2023-01-11 Strengthening Pi standoffs
    [Panels.FCStd]
2023-01-12 Adjust Pi standoff for case
    [Panels.FCStd]
2023-01-12 Tiny display
    [Panels.FCStd]
2023-01-26 Power Management module
    [PowerOn print.kicad_pcb, PowerOn print.kicad_sch]
2023-01-28 Redesign Poweron system
    [PowerOn print.kicad_pcb, PowerOn print.kicad_sch]
2023-01-29 Poweron print adapted
    [Cyberdeck.FCStd, PowerOn print.kicad_pcb, PowerOn print.kicad_sch]
2024-11-04 New power print
    [Power print.kicad_pcb, Power print.kicad_sch, PowerOn print.kicad_sch]
2024-11-04 Push button circuit
2024-11-04 Updated PowerOn print
2024-11-13 Power print resistor added
    [Power print.kicad_sch]
2024-11-13 Schematics power mgmnt Pi
    [Power print.kicad_pcb, Power print.kicad_sch]
2024-11-13 Added title for power measurement
    [Power print.kicad_sch]
2024-11-15 Power print schematics
    [Power print.csv, Power print.kicad_pcb, Power print.kicad_sch]
2024-11-17 PCB design
    [Micro Controller.kicad_sch, Power print.kicad_pcb, Power print.kicad_sch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]
2024-11-18 Rotated power connector
    [Power print.kicad_pcb, Power print.kicad_sch]
2025-04-13 update schema
    [Power print.kicad_sch]
